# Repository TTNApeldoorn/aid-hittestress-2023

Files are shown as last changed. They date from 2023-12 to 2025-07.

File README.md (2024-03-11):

# aid-hittestress-2023

These climate sensors are designed for the Homerus-Energiek project in Apeldoorn. They measures temperature, humidity and air quality.
The sensors are mounted in lampposts and communicate via LoRAWan with the TTN network.

## Requirements 
- The sensor measures each 2 minutes temperatue, humidity and particular matter PM1.0, 2.5 and 10
- The sensor sends the measurements to the TTN network using LoRaWan radio
- The sensor can be mounted on lamppost (case IP65)
- The sensor operates on LiPo battery (for minimal 18 hours) and can be charged by 230V supply 
- The sensor battery is charged at night by the lamppost
- GPS location and battery voltage are reported at regular intervals

## Realization

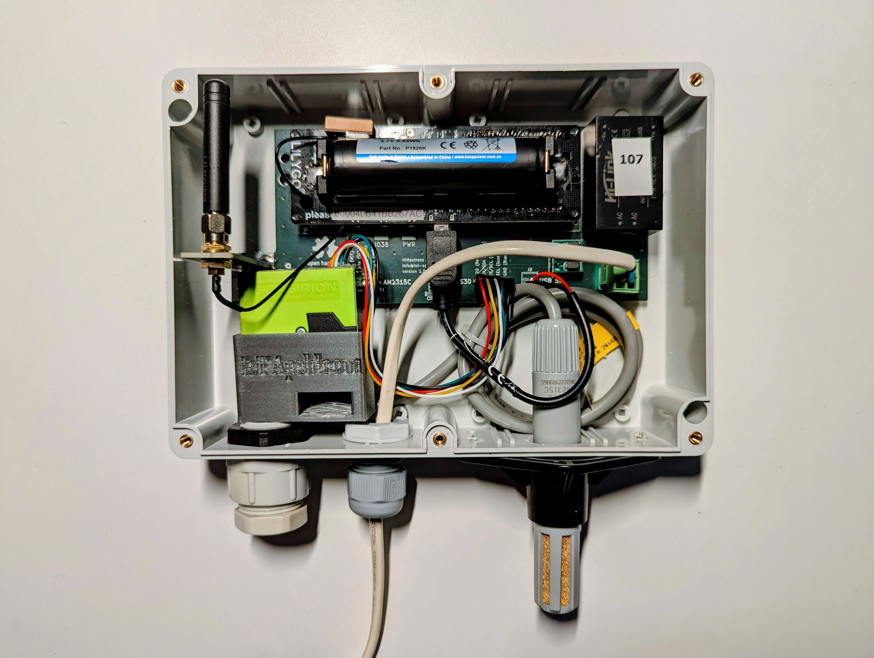
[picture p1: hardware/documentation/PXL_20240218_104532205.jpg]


 Climate Sensor in Kradex housing

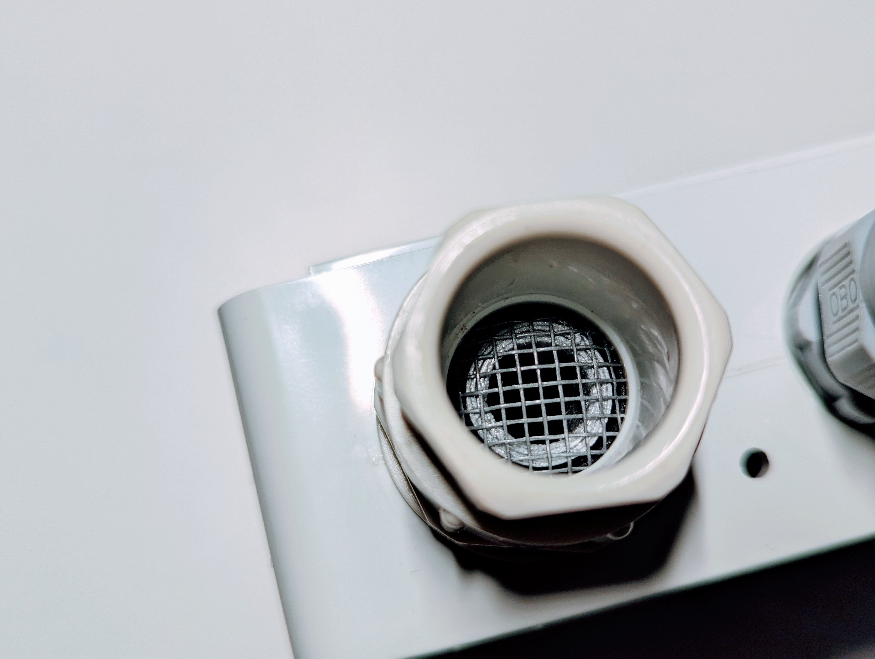
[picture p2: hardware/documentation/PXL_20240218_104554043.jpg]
 

Air inlet dust sensor, with insect sreen

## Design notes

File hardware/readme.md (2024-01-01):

# Homerus Klimaat sensor 2023
Notes on hardware for Homerus Klimaatsensor. 

## Hardware

Ik heb de software nu draaiend, met deepsleep en interne GPS,  met  SPS30 en AM2315 op de i2c.
De AM2315 en SPS30 zitten parallel op de I2C bus als volgt:
 pin 21 SDA
 pin 22 SCL
 AM2315 power op 3V3
 SDS30 power nu op de 5v pin, deze zakt naar 4v als het board op de batterij draait, dus volgens de specs net niet genoeg. Hiervoor moet dus een step-up naar 5v bij geplaatst worden.

Het board draait nu 24 uur op de batterij, en Vbat is van 4,095V nu gezakt naar 3,898V. Volgens mij houdt die het wel een tijdje uit op de batterij.

De 5v pin op het TTGO board is een 5v output pin, en geen 5v input. Dus de externe 5v voeding moet aangesloten worden op de micro USB connector, anders werkt het laad circuit niet.

https://github.com/Xinyuan-LilyGO/LilyGo-LoRa-Series

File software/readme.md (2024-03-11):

# Homerus Climate sensor 2023
These climate sensors are designed for the Homerus-Energiek project in Apeldoorn.

## Hardware:
- LilyGO TTGO T-Beam - LoRa 868MHz - NEO-M8N GPS - ESP32 
- Sensirion SPS30 Particulate matter sensor i2c
- AM2315C Temperature/humidity sensor i2c
- 18650 Li-ion Batterij - 2600mAh
- Hi-Link PCB Voeding - 5VDC 1A
- Mini DC-DC 5V Step-up Boost Converter 480mA
- PCB for connecting components
- Kradex housing 176x126x57mm - IP65

There are 2 types of TTGO T-Beam versions:
- TTGO T-Beam V1.2 with LoRa SX1262
- TTGO T-Beam V1.2 with LoRa SX1276

For this reason we use the LoRa LacunaSpace basicmac library wich supports both LoRa chips SX1262 and SX1276

## Software 

### Prerequisites:
- Visual Studio with Platform IO
- LacunaSpace/basicmac LoRa library
- mikalhart/TinyGPSPlus GPS library
- sensirion/sensirion-sps particicle matter SPS30 library
- lewisxhe/AXP202X_Library power control T-Beam
- RobTillaart/AM2315C library for the i2c AM2315C sensor
- espressif32@3.5.0 platform with board ttgo-t-beam

All libraries are defined in paltformio.ini and will be loaded automatically when the project is opened, except for the LacunaSpace/basicmac LoRa library.

### Install LacunaSpace/basicmac manually
Download the LacunaSpace/basicmac zip library from https://github.com/LacunaSpace/basicmac.
Run the script ./target/arduino/export.sh or ./target/arduino/export.bat to export the necessary files to a specific location. Specify this location in your platformio.ini file.

## Instructions
### Change the parameters in the basicmap library if necesssary.
In the file hal/target-config.h some parameters are defined, defaults are:
> #define CFG_eu868 1  
> #define BRD_sx1262_radio 1

Change the paramaters by (un)commenting those lines accodingly, if you have a sx1276 board or you are outside Europe.

### LoRaWan TTN keys
In the file configuration.h the TTN keys APPEUI an APPKEY are defined.
The unique DEVEUI key is obtained from the T-BEAM board id.

## TTN interface
Two type of messages are sent by the sensor:
- measurement report (each 2 minutes), send on TTN port 15
- status report (eachtime after 100 measurement reports), send on TTN port 16

Measurement report contains:
- temperature in C
- Relative Humidity in %
- Particulate Matter 1.0 μg/m3
- Particulate Matter 2.5 μg/m3
- Particulate Matter 10 μg/m3
- Battery voltage in V

Status report contains:
- GPS position lat/lon, hdop, altitude
- Sensor version
- batterij voltage

The binary messages from the Sensor are converted by the TTN Payloaddecoder into Json.  
Example JSON measurement message:

> {"pm10":8.5,"pm1p0":7.22,"pm2p5":8.02,"rh":99.99,"temp":7.82,"vbat":4.037}

Example JSON status message:
> {"latitude":52.224578,"longitude":6.0061902,"alt":0.0,"hdop":1.61,vbat":4.099,"SwVer":3.02 }

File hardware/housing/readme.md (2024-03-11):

# Drill plan housing
This is the [drillplan](DrillPlanHousing_001.png) for the housing. 
The drill plan shows the bottom plane of a [Kradex Z74 ABS enclosure](../documentation/Z74.pdf).
The drawing can be found in documentation.

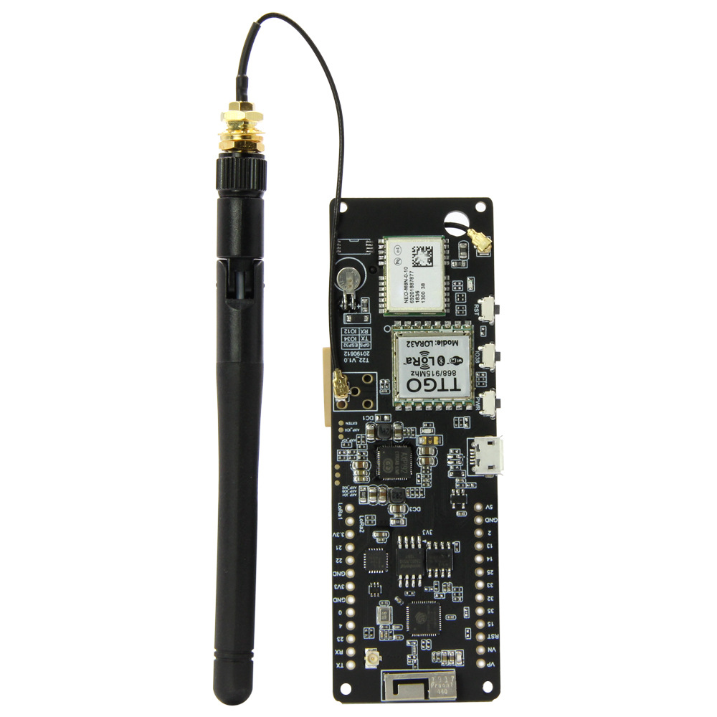
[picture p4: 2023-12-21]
hardware/documentation/LILYGO-H261_1.jpg

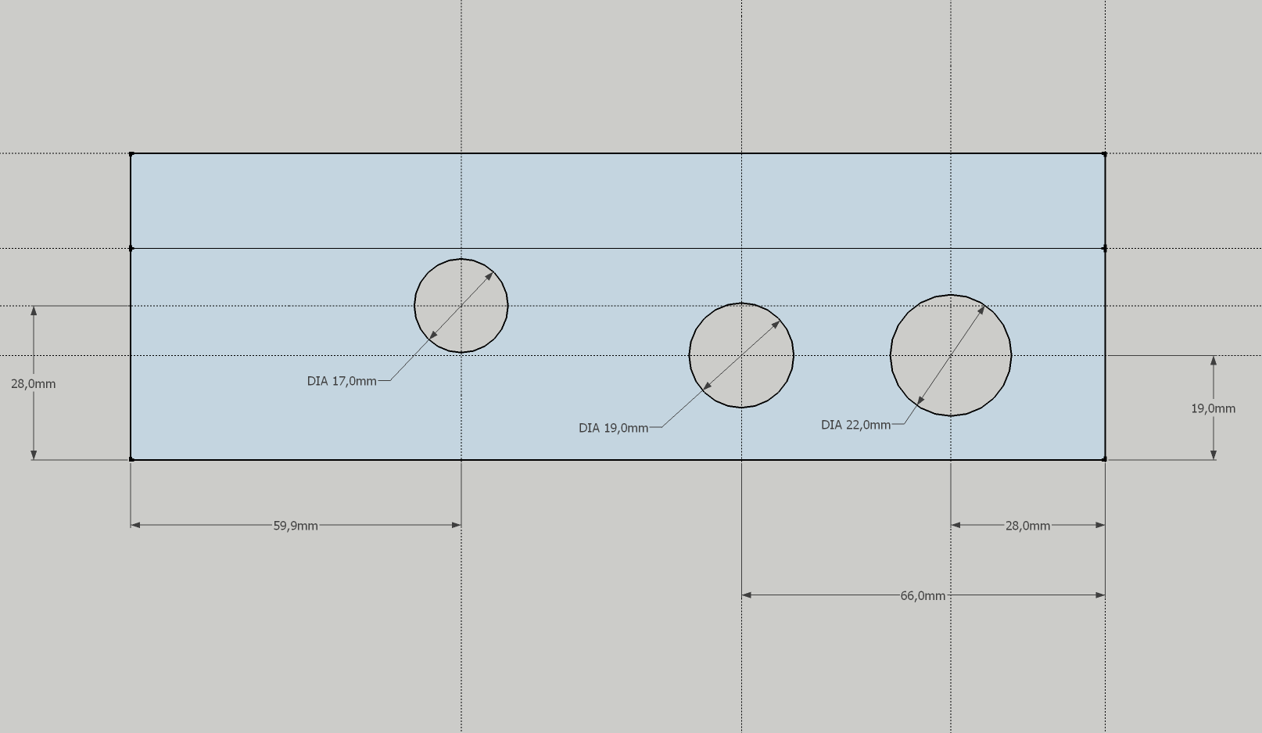
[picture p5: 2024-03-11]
hardware/housing/DrillPlanHousing_001.png

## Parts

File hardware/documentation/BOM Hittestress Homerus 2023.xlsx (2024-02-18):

LilyGO TTGO T-Beam-LoRa 868MHz-NEO-M8N GPS | Tinytronics | 40.5 | https://www.tinytronics.nl/shop/nl/development-boards/microcontroller-boards/met-gps/lilygo-ttgo-t-beam-v1.0-lora-868mhz-neo-6m-gps-esp32
Kradex ABS IP65, afmeting 126mm x 176mm x 55mm | Tinytronics | 10 | https://www.tinytronics.nl/shop/nl/gereedschap-en-montage/behuizingen/universeel/kradex-behuizing-176x126x57mm-ip65-grijs-z74jh-tm-abs
kabelwartel 8-12mm | Tinytronics | 0.85 | https://www.tinytronics.nl/shop/nl/gereedschap-en-montage/installatie-en-montagemateriaal/wartels/kabelwartel-m25-12mm-18mm
AM2315 | Bits & parts | 19.95 | https://www.bitsandparts.nl/Temperatuursensor-en-luchtvochtigheidssensor-AM2315-I2C-p1091105?gad_source=1
4 Pin Schroef Terminal Block Connector 2.54mm | Tinytronics | 0.45 | https://www.tinytronics.nl/shop/nl/kabels-en-connectoren/connectoren/schroefterminals/4-pin-schroef-terminal-block-connector-2.54mm-afstand
voedingsmodule 230V to 5V HLK-5M05 | Tinytronics | 6 | https://www.tinytronics.nl/shop/nl/power/voedingen/5v/hi-link-pcb-voeding-5vdc-1a-hlk-5m05
Keeppower 18650 Li-ion Batterij - 2600mAh | Tinytronics | 8 | https://www.tinytronics.nl/shop/nl/power/batterijen/18650/keeppower-18650-li-ion-batterij-2600mah-5.2a
sps30 sensirion | SOS electronics | 34.68 | https://www.soselectronic.com/en/products/sensirion/sps30-2-304234?vat=1&gad_source=1
Mini DC-DC 5V Step-up Boost Converter 480mA | Tinytronics | 2 | https://www.tinytronics.nl/shop/nl/power/spanningsconverters/boost-(step-up)-converters/mini-dc-dc-5v-step-up-boost-converter-480ma
Micro USB stekker | reichelt | 1.07 | https://www.reichelt.nl/nl/nl/micro-usb-stekker-type-b-5-polig-usb-micro-st-p124013.html?PROVID=2809
JST-ZHR 5p to DuPont Femal | Tinytronics | 1 | https://www.tinytronics.nl/shop/en/cables-and-connectors/cables-and-adapters/jst-compatible/jst-zhr-5p-to-dupont-female-compatible-cable-15cm
Afneembare Schroefterminal - 2p – 3.81mm | Tinytronics | 0.45 | https://www.tinytronics.nl/shop/nl/kabels-en-connectoren/connectoren/schroefterminals/afneembare-schroefterminal-2p-3.81mm
Terminal Block voor Afneembare Schroefterminal - 2p – 3.81mm | Tinytronics | 0.4 | https://www.tinytronics.nl/shop/nl/kabels-en-connectoren/connectoren/schroefterminals/terminal-block-voor-afneembare-schroefterminal-2p-3.81mm
printplaat bij 9 stuks | ? | 7
zelfherstellende zekering Lvr005 240V 50mA | Ali express / RS | 1
C’s 100nf + 100uf |  | 1
3d houder voor sps30 | JENG IoT | 0
Verzendkosten (4 x 7)/6 |  | 5
Micro USB verloopkabel | Allekabels.nl | 4.69 | https://www.allekabels.nl/usb-micro-kabel/4911/2302010/micro-usb-kabel.html
Kosten 1 extra bouwen t.b.v. prototype / onderhoud + 100%/6 |  | 25
Onvoorzien 10% |  | 15
 |  | 184.04
DELOCK 82697 USB 2.0 micro-B stekker> 2 x open kabeleinde | Reichelt | 3 | https://www.reichelt.nl/nl/nl/usb-2-0-micro-b-stekker-2-x-open-kabeleinde-delock-82697-p163750.html

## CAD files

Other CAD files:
hardware/housing/DrillPlanHousing_001.skp

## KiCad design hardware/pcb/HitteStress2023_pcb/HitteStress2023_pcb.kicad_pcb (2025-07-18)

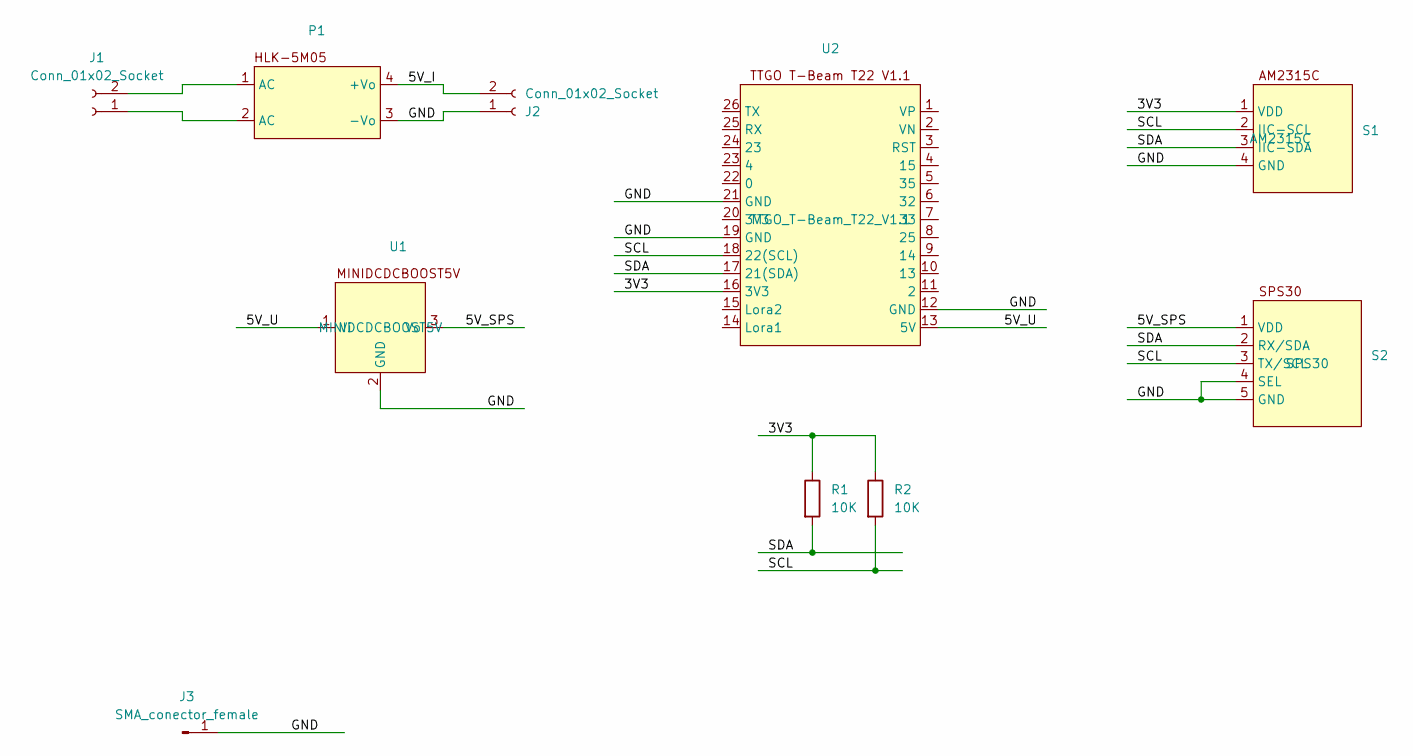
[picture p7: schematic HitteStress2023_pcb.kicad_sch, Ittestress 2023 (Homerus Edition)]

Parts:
J1: Conn_01x02_Socket; PhoenixContact_MCV_1,5_2-G-5.08_1x02_P5.08mm_Vertical
J2: Conn_01x02_Socket; TerminalBlock_Phoenix_MPT-0,5-2-2.54_1x02_P2.54mm_Horizontal
J3: SMA_conector_female; SMA-ANT-CONN
P1: HLK-5M05
R1, R2: 10K; R_Axial_DIN0309_L9.0mm_D3.2mm_P12.70mm_Horizontal
S1: AM2315C
S2: SPS30
U1: MINIDCDCBOOST5V
U2: TTGO_T-Beam_T22_V1.1

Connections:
/3V3: R1.1, R2.1, S1.1 (VDD), U2.16 (3V3)
/5V_I: J2.2, P1.4 (+Vo)
/5V_SPS: S2.1 (VDD), U1.3 (Vo)
/5V_U: U1.1 (Vi), U2.13 (5V)
/GND: J2.1, J3.1, P1.3 (-Vo), S1.4 (GND), S2.4 (SEL), S2.5 (GND), U1.2 (GND), U2.12 (GND), U2.19 (GND), U2.21 (GND)
/SCL: R2.2, S1.2 (IIC-SCL), S2.3 (TX/SCL), U2.18 (22(SCL))
/SDA: R1.2, S1.3 (IIC-SDA), S2.2 (RX/SDA), U2.17 (21(SDA))
unnamed: J1.1, P1.2 (AC)
unnamed: J1.2, P1.1 (AC)

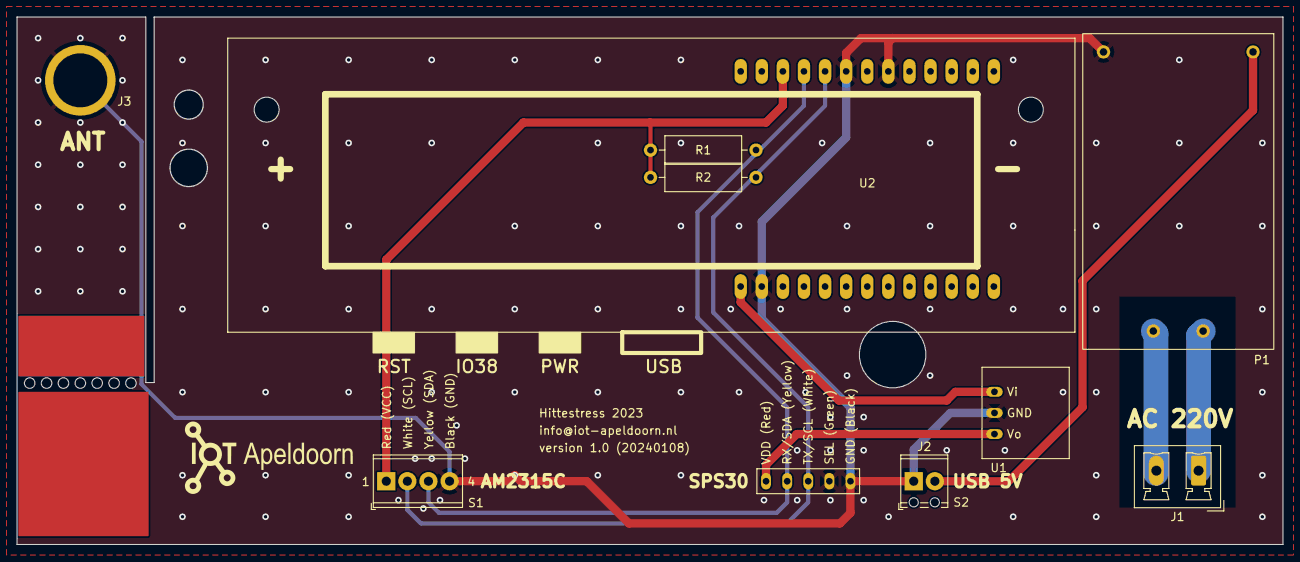
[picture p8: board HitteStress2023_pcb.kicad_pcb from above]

Board: 2 copper layers, 152.4 x 63.5 mm, 10 parts (0 on the bottom side), 9 nets.

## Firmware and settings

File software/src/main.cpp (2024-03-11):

/*

  Main module

  # Modified by Kyle T. Gabriel to fix issue with incorrect GPS data for TTNMapper

  Copyright (C) 2018 by Xose Pérez <xose dot perez at gmail dot com>

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
  You should have received a copy of the GNU General Public License
  along with this program.  If not, see <http://www.gnu.org/licenses/>.
*/

#include "configuration.h"
#include "rom/rtc.h"
#include <Wire.h>
#include "axp20x.h"
#include "AM2315C.h"
#include "ttn.h"
#include "gps.h"
#include "mysps30.h"

AXP20X_Class axp;
bool pmu_irq = false;

bool packetSent = false, packetQueued = false;
bool sensorCycle = false, gpsCycle = false;
int start;

// deep sleep support
RTC_DATA_ATTR int bootCount = 0;
esp_sleep_source_t wakeCause;  // the reason we booted this time

// payload structs
struct Msg {
  int16_t temp, hum, pm2_5, pm10, batt, pm1_0;
};
static Msg msg = {0, 0, 0, 0, 0, 0}; 

struct Stat {
  float lat, lng;
  int16_t alt, hdop, batt, version, cputemp;
};
static Stat stat = {0.0, 0.0, 0, 0, 0, 0, 0}; 

// Sensors
Gps gps;          // GPS sensor
AM2315C am2315;  // temperature hum sensor
Sps30 sps30;     // dust sensor

// -----------------------------------------------------------------------------
// Application
// -----------------------------------------------------------------------------

/**
 * sleep, turn off LORA and GPS power
 */
void sleep(int msec) {
  printf("sleep for %d\n", msec);
  // Set the user button to wake the board
  esp_sleep_enable_ext0_wakeup((gpio_num_t)BUTTON_PIN, LOW);  //sleep_interrupt(BUTTON_PIN, LOW);
  ttn_shutdown();                                            // cleanly shutdown the radio

  // turn on after initial testing with real hardware
  axp.setPowerOutPut(AXP192_LDO2, AXP202_OFF);  // LORA radio
  axp.setPowerOutPut(AXP192_LDO3, AXP202_OFF);  // GPS main power

  // FIXME - use an external 10k pulldown so we can leave the RTC peripherals powered off
  // until then we need the following lines
  esp_sleep_pd_config(ESP_PD_DOMAIN_RTC_PERIPH, ESP_PD_OPTION_ON);

  // Only GPIOs which are have RTC functionality can be used in this bit map: 0,2,4,12-15,25-27,32-39.
  uint64_t gpioMask = (1ULL << BUTTON_PIN);

  // FIXME change polarity so we can wake on ANY_HIGH instead - that would allow us to use all three buttons (instead of just the first)
  gpio_pullup_en((gpio_num_t)BUTTON_PIN);
  esp_sleep_enable_ext1_wakeup(gpioMask, ESP_EXT1_WAKEUP_ALL_LOW);

  esp_sleep_enable_timer_wakeup(msec * 1000ULL);  // call expects usecs
  esp_deep_sleep_start();
}

void _txCallback() {
  // We only want to say 'packetSent' for our packets (not packets needed for joining)
  if (packetQueued) {
    printf("Message sent\n");
    packetQueued = false;
    packetSent = true;
  }
}

void _rxCallback(unsigned int port, uint8_t* buf, unsigned int len) {
  printf("[TTN] Response: ");
  for (int i = 0; i < len; i++) {
    printf("%02x ", buf[i]);
  }
  printf("\n");
}

/**
 * Init the power manager chip
 * 
 * axp192 power 
    DCDC1 0.7-3.5V @ 1200mA max -> OLED  // If you turn this off you'll lose comms to the axp192 because the OLED and the axp192 share the same i2c bus, instead use ssd1306 sleep mode
    DCDC2 -> unused
    DCDC3 0.7-3.5V @ 700mA max -> ESP32 (keep this on!)
    LDO1 30mA -> charges GPS backup battery  // charges the tiny J13 battery by the GPS to power the GPS ram (for a couple of days), can not be turned off
    LDO2 200mA -> LORA
    LDO3 200mA -> GPS
 */

void axp192Init() {
  if (!axp.begin(Wire, AXP192_SLAVE_ADDRESS)) {
    Serial.println("AXP192 Begin PASS");
  } else {
    Serial.println("AXP192 Begin FAIL");
    return;
  }
  //axp.setChgLEDMode(LED_BLINK_4HZ);
  //printf("DCDC1=%d, DCDC2=%d, LDO2=%d, LDO3=%d, DCDC3=%d, EXten=%d\n",
  //       axp.isDCDC1Enable(), axp.isDCDC2Enable(), axp.isLDO2Enable(), axp.isLDO3Enable(), axp.isDCDC3Enable(), axp.isExtenEnable());

  axp.setPowerOutPut(AXP192_LDO2, AXP202_ON);  // LORA radio
  //axp.setPowerOutPut(AXP192_LDO3, AXP202_ON);  // GPS main power
  axp.setPowerOutPut(AXP192_DCDC2, AXP202_ON);
  axp.setPowerOutPut(AXP192_EXTEN, AXP202_ON);
  axp.setPowerOutPut(AXP192_DCDC1, AXP202_ON);
  axp.setDCDC1Voltage(3300);  // for the OLED power

 //printf("DCDC1=%d, DCDC2=%d, LDO2=%d, LDO3=%d, DCDC3=%d, EXten=%d\n",
 //        axp.isDCDC1Enable(), axp.isDCDC2Enable(), axp.isLDO2Enable(), axp.isLDO3Enable(), axp.isDCDC3Enable(), axp.isExtenEnable());

//  int cur = axp.getChargeControlCur();
//  Serial.printf("Current charge control current = %d mA \n", cur);
  //axp.setChargeControlCur( 15);
  //Serial.printf("Set charge control current 500 mA \n");
  //cur = axp.getChargeControlCur();
 // Serial.printf("Current charge control current = %d mA \n", cur);
 
  pinMode(PMU_IRQ, INPUT_PULLUP);
  attachInterrupt(
    PMU_IRQ, [] {
      pmu_irq = true;
    },
    FALLING);

  axp.adc1Enable(AXP202_BATT_CUR_ADC1, 1);
  axp.enableIRQ(AXP202_VBUS_REMOVED_IRQ | AXP202_VBUS_CONNECT_IRQ | AXP202_BATT_REMOVED_IRQ | AXP202_BATT_CONNECT_IRQ, 1);
  axp.clearIRQ();
/*
  if (axp.isChargeing()) {
    Serial.printf("Charging\r\n");
  } */
}

void setup() {
  Serial.begin(115200);
  delay(200);
 
  if( bootCount >= 1000)   // force a new join after n cycles
    bootCount = 1;
  else
   bootCount++;

  wakeCause = esp_sleep_get_wakeup_cause();
  Serial.printf("booted, wake cause %d (boot count %d)\n", wakeCause, bootCount);

  Wire.begin(I2C_SDA, I2C_SCL);
  axp192Init();

  // Buttons & LED
  pinMode(BUTTON_PIN, INPUT_PULLUP);

  // TTN setup
  if (bootCount == 1)
    ttn_erase_prefs();

  if (!ttn_setup()) {
    printf("Radio module not found!\n");
    sleep( 60000);  //deepsleep retry afer one minute
  }
  ttn_register_rxReady(_rxCallback);
  ttn_register_txReady(_txCallback);

  // init and read sensors
  if (bootCount % 100) {      // send after n sensor messages a status message
    sensorCycle = true;
    // read dust
    if( sps30.init() && sps30.read() ) {
      msg.pm1_0 = sps30.pm1_0 * 100;
      msg.pm2_5 = sps30.pm2_5 * 100;
      msg.pm10 = sps30.pm10 * 100;
      printf("pm1=%d pm2.5=%d pm10=%d\n", msg.pm1_0, msg.pm2_5, msg.pm10);
    }
    // read temperature and humidity
    if( am2315.begin() && am2315.read() == AM2315C_OK) {
      msg.temp = am2315.getTemperature() * 100;
      msg.hum = am2315.getHumidity() * 100;
      printf("temp=%d  hum=%d\n", msg.temp, msg.hum );
    }
    msg.batt = (int16_t)axp.getBattVoltage();
    printf("BattVoltage = %d\n", msg.batt);
  }
  // send status and gps position
  else {
    axp.setPowerOutPut(AXP192_LDO3, AXP202_ON); // set GPS POWER on
    gpsCycle = true;
    gps.init();
    gps.read();
    stat.lat = gps.lat;
    stat.lng = gps.lng;
    stat.hdop =gps.hdop;
    stat.alt = gps.alt;
    stat.version = APP_VERSION * 100;
    stat.batt = (int16_t)axp.getBattVoltage();
    stat.cputemp = (int16_t)axp.getTemp() * 100;
  }
  start = millis();
  printf("setup end\r\n");
}

void loop() {

  ttn_loop();

  if( ttn_connected() && !packetQueued && !packetSent) {
    //printf("ttn_send\n");
    if( sensorCycle )
      ttn_send((uint8_t*)&msg, sizeof(msg), 15);
    else
      ttn_send((uint8_t*)&stat, sizeof(stat), 16);
    packetQueued = true;
  }

  // if packet has been sent, or wait max 10 sec for completing the ttn msg, then start deepsleep
  if( packetSent  || millis() - start > 10000) {
    packetSent = false;
    
    if( gpsCycle )
      sleep( 10000);           // minimum sleep time
    else
      sleep( SEND_INTERVAL - 10000);
  }
}

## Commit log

2023-12-20 Started drawing
    [HitteStress2023_pcb.kicad_sch]
2023-12-20 Drawing progress, added mandatory component to BOM Hittestress Homerus 2023.xlsx
    [BOM Hittestress Homerus 2023.xlsx, HitteStress2023_pcb.kicad_sch]
2023-12-21 Update drawing
    [HitteStress2023_pcb.kicad_pcb, HitteStress2023_pcb.kicad_sch]
2023-12-21 Finalised the day
    [HitteStress2023_pcb.kicad_sch]
2023-12-21 Update footprints
2023-12-22 Updated 3D representation
    [HitteStress2023_pcb.kicad_pcb]
2023-12-22 Update design with IoT-Apeldoorn logo
    [HitteStress2023_pcb.kicad_pcb]
2023-12-25 Updated PCB
    [HitteStress2023_pcb.kicad_pcb, configuration.h]
2024-01-01 Verified and updated to v0.9 for first prototype print and ordered it.
    [HitteStress2023_pcb.kicad_pcb, HitteStress2023_pcb.kicad_sch]
2024-01-08 Version 1.0 after prototype soldering
    [BOM Hittestress Homerus 2023.xlsx, HitteStress2023_pcb.kicad_pcb, HitteStress2023_pcb.kicad_sch]
2024-02-29 Add files via upload
    adapted for Visual Studio and LoRa libs changed to basicmac
    [configuration.h]
2024-03-11 Added drill plan for housing.
    [DrillPlanHousing_001.skp]
2025-07-18 Added 2x pull-pup resistors for I2C
    [HitteStress2023_pcb.kicad_pcb, HitteStress2023_pcb.kicad_sch]

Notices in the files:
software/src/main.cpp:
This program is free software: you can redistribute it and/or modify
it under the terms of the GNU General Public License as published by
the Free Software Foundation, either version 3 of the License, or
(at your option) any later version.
